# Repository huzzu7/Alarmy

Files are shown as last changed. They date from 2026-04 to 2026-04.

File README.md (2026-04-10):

# Alarmy

An Arduino-based running alarm clock that combines standard alarm clock functionality with motion, proximity sensing, and embedded UI design.

Alarmy was built as an embedded design project with the goal of making alarms harder to ignore. The system keeps real time using a DS1302 RTC, allows the user to set the clock and alarm through a rotary encoder and buttons, stores alarm settings in EEPROM, drives a buzzer and motor for alarm output, and uses an IR emitter and photodiode sensing setup for proximity detection.

## Features

- Real-time clock using a **DS1302 RTC**
- 16x2 **Waveshare RGB LCD** interface
- **KY-040 rotary encoder** with pushbutton for editing values
- External pushbutton for mode changes and alarm dismissal
- **Weekday-based alarm scheduling**
- **EEPROM-backed alarm persistence**
- Passive buzzer alarm output
- N20 motor-based physical alarm actuation
- IR emitter and photodiode proximity sensing using an **LM393 comparator board**
- Interrupt-based rotary encoder handling with Gray-code decoding
- Optimized LCD updates to reduce flicker and improve responsiveness

## Repository Structure

```text
Alarmy/
├── media/      # Project photos / demo images
├── cad/        # Mechanical design files / 3D models
├── pcb/        # PCB design files
└── src/
    └── alarmy.ino
```

## Hardware

Current hardware used in the prototype:

- Arduino Uno
- DS1302 RTC module
- Waveshare RGB LCD1602
- KY-040 rotary encoder
- External pushbutton
- Passive buzzer
- N20 DC motor
- MOSFET motor driver
- Flyback diode
- IR emitter and photodiode
- KY-037 board repurposed for its onboard LM393 comparator
- 470 µF bulk capacitor for voltage sag protection
- 0.1 µF capacitor for pushbutton RC filtering
- NiMH battery supply

## How It Works

The firmware is organized around three main UI modes:

- `MODE_NORMAL`
- `MODE_SET_TIME`
- `MODE_SET_ALARM`

The user edits values using the rotary encoder and its pushbutton, while the external button is used for major mode transitions. The RTC is polled periodically, alarm settings are stored in EEPROM, and the LCD only redraws changed characters to reduce flicker. The alarm logic supports weekday selection through a 7-bit day mask, and the buzzer uses a non-blocking repeating beep pattern. The motor output is also integrated into the alarm behavior.

## Pin Summary

From the current firmware:

- `pinA = 2`
- `pinB = 3`
- `buttonPin = A0`
- `rotButtonPin = 4`
- `buzzer = 8`
- `emitterPin = 9`
- `sensorPin = A1`
- `motorPin = 5`

RTC pins:

- `CE = 10`
- `IO = 11`
- `SCLK = 12`

## Software Notes

A few implementation details that matter:

- Rotary encoder input is handled using **interrupts**
- Encoder transitions are decoded using a **Gray-code transition table**
- Alarm settings are stored in EEPROM using a **versioned structure**
- LCD updates are throttled and diff-based to improve responsiveness
- Proximity detection compares emitter-off and emitter-on readings rather than relying on a single absolute measurement

## Building / Uploading

1. Open `src/alarmy.ino` in the Arduino IDE.
2. Install the required libraries:
   - `DS1302`
   - `EEPROM` (built-in)
   - `Waveshare_LCD1602_RGB`
3. Select the correct board and port for your Arduino.
4. Upload the sketch.
5. Connect the hardware according to the pin assignments above.

## CAD and PCB

- The `cad/` folder contains the mechanical design files for the enclosure and body.
- The `pcb/` folder contains the board design files as the electronics become more integrated.

The long-term goal is to move away from multiple header-connected external modules and toward a more compact PCB with more of the support circuitry integrated directly on-board.

## Media

Prototype photo:

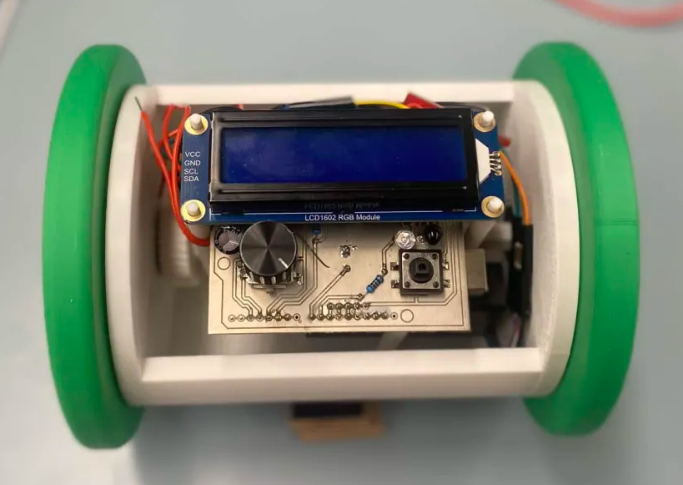
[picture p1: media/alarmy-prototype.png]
Alarmy prototype


PCB screenshot:

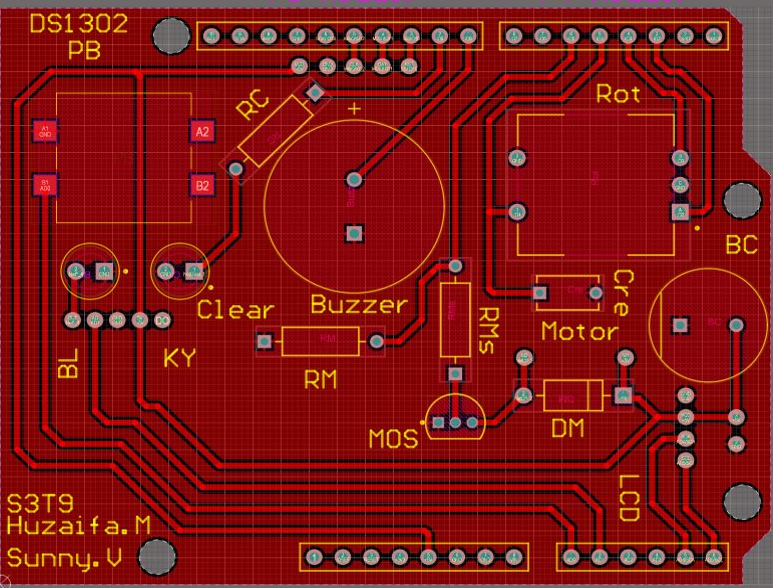
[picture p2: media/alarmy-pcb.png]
Alarmy screenshot


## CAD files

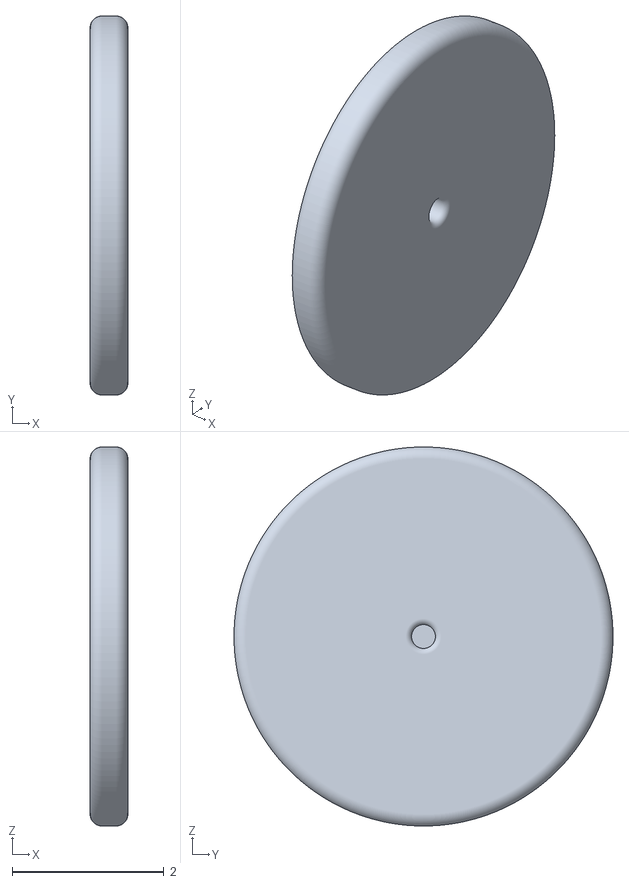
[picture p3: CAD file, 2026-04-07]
cad/wheel.stl
0.5 x 5.00 x 5.00

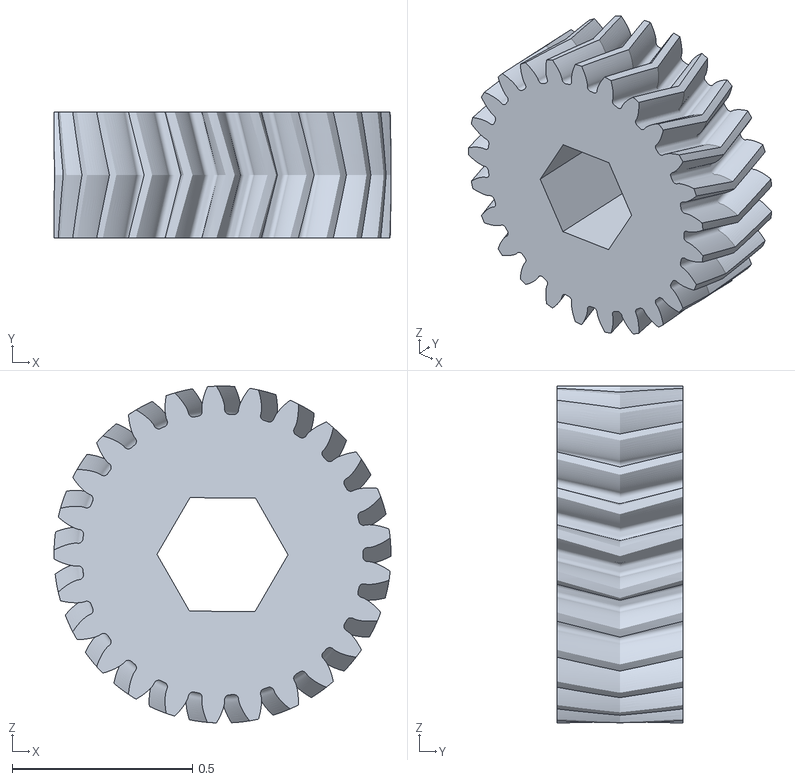
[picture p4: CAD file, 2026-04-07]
cad/driven_gear.stl
0.935 x 0.35 x 0.935

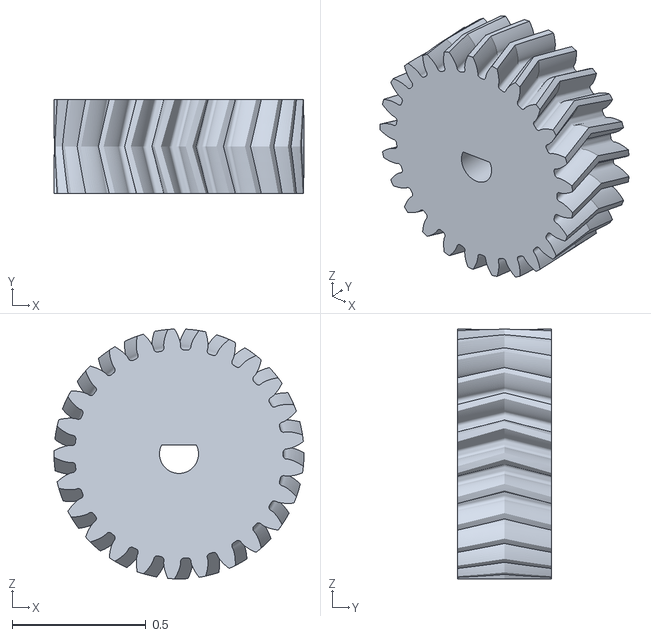
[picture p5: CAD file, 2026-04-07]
cad/driving_gear.stl
0.935 x 0.35 x 0.935

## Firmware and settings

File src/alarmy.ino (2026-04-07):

#include <Wire.h>
#include <EEPROM.h>
#include "Waveshare_LCD1602_RGB.h"
#include <DS1302.h>

// ---------------- Pins ----------------
const int pinA = 2;
const int pinB = 3;
const int buttonPin = A0;
const int rotButtonPin = 4;
const int buzzer = 8;
const int emitterPin = 9;
const int sensorPin = A1;
const int motorPin = 5;

// ---------------- DS1302 pins ----------------
const int kCePin   = 10;
const int kIoPin   = 11;
const int kSclkPin = 12;

DS1302 rtc(kCePin, kIoPin, kSclkPin);

// ---------------- LCD ----------------
Waveshare_LCD1602_RGB lcd(16, 2);

// ---------------- Custom underlined weekday chars ----------------
// slots:
// 0 = M
// 1 = T
// 2 = W
// 3 = F
// 4 = S
byte UL_M[8] = {
  B10001,
  B11011,
  B10101,
  B10001,
  B10001,
  B10001,
  B00000,
  B11111
};

byte UL_T[8] = {
  B11111,
  B00100,
  B00100,
  B00100,
  B00100,
  B00100,
  B00000,
  B11111
};

byte UL_W[8] = {
  B10001,
  B10001,
  B10001,
  B10101,
  B10101,
  B01010,
  B00000,
  B11111
};

byte UL_F[8] = {
  B11111,
  B10000,
  B10000,
  B11110,
  B10000,
  B10000,
  B00000,
  B11111
};

byte UL_S[8] = {
  B01111,
  B10000,
  B10000,
  B01110,
  B00001,
  B00001,
  B11110,
  B11111
};

// ---------------- Modes ----------------
enum UiMode {
  MODE_NORMAL,
  MODE_SET_TIME,
  MODE_SET_ALARM
};

UiMode mode = MODE_NORMAL;

// ---------------- Current time/date ----------------
int currentHour = 14;
int currentMinute = 30;
int currentDay = Time::kSunday;
int currentMonth = 3;
int currentDate = 15;
int currentYear = 2026;

// ---------------- Alarm ----------------
int alarmHour = 7;
int alarmMinute = 0;

// bit0=Mon, bit1=Tue, ..., bit6=Sun
uint8_t alarmDaysMask = 0x7F;

// ---------------- Photodiode sensing ----------------
int baselineSignal = 0;
const int buffer = 50;
const int detectionThreshold = 100;
bool proxDetected = false;
unsigned long lastProximitySample = 0;
const unsigned long proximitySamplePeriodMs = 15;

// ---------------- EEPROM layout ----------------
struct AlarmDataV2 {
  uint8_t magic;
  uint8_t hour;
  uint8_t minute;
  uint8_t daysMask;
};

struct AlarmDataV1 {
  uint8_t magic;
  uint8_t hour;
  uint8_t minute;
};

const uint8_t ALARM_MAGIC_V2 = 0xA8;
const uint8_t ALARM_MAGIC_V1 = 0xA7;
const int EEPROM_ADDR_ALARM = 0;

// ---------------- Button state ----------------
int lastButtonState = HIGH;
int lastRotButtonState = HIGH;
unsigned long lastButtonTime = 0;
unsigned long lastRotButtonTime = 0;
const unsigned long buttonDebounceMs = 30;

// ---------------- Encoder state ----------------
volatile int8_t encoderAcc = 0;
volatile uint8_t encoderState = 0;

const int8_t transitionTable[16] = {
  0, +1, -1,  0,
  -1,  0,  0, +1,
  +1,  0,  0, -1,
   0, -1, +1,  0
};

// ---------------- UI state ----------------
// MODE_SET_TIME:
// 0 = hours, 1 = minutes, 2 = AM/PM, 3 = day, 4 = month, 5 = date
//
// MODE_SET_ALARM:
// 0 = hours, 1 = minutes, 2 = AM/PM,
// 3 = Mon, 4 = Tue, 5 = Wed, 6 = Thu, 7 = Fri, 8 = Sat, 9 = Sun
int editIndex = 0;

// ---------------- LCD refresh control ----------------
bool displayDirty = true;
UiMode lastRenderedMode = MODE_SET_ALARM;
unsigned long lastLcdUpdate = 0;
const unsigned long lcdUpdatePeriod = 50;

// ---------------- Software blink ----------------
bool blinkVisible = true;
unsigned long lastBlinkToggle = 0;
const unsigned long blinkPeriod = 400;

// ---------------- LCD line cache ----------------
char lastLine1[17] = "                ";
char lastLine2[17] = "                ";

// ---------------- RTC sync timing ----------------
unsigned long lastRtcPoll = 0;
const unsigned long rtcPollPeriodMs = 250;

// ---------------- Helpers ----------------
void fillLine(char *line) {
  for (int i = 0; i < 16; i++) line[i] = ' ';
  line[16] = '\0';
}

bool fallingEdgeDebounced(int pin, int &lastState, unsigned long &lastTimeMs) {
  int currentState = digitalRead(pin);
  bool fell = false;

  if (lastState == HIGH && currentState == LOW) {
    unsigned long now = millis();
    if (now - lastTimeMs >= buttonDebounceMs) {
      fell = true;
      lastTimeMs = now;
    }
  }

  lastState = currentState;
  return fell;
}

int getDisplayHour12From(int hour24) {
  int h = hour24 % 12;
  if (h == 0) h = 12;
  return h;
}

bool isPMFrom(int hour24) {
  return hour24 >= 12;
}

void setFromDisplayHour12AndPeriod(int displayHour12, bool pm, int &hour24) {
  if (displayHour12 == 12) {
    hour24 = pm ? 12 : 0;
  } else {
    hour24 = pm ? (displayHour12 + 12) : displayHour12;
  }
}

const char* dayShort(uint8_t day) {
  switch (day) {
    case Time::kSunday:    return "Sun";
    case Time::kMonday:    return "Mon";
    case Time::kTuesday:   return "Tue";
    case Time::kWednesday: return "Wed";
    case Time::kThursday:  return "Thu";
    case Time::kFriday:    return "Fri";
    case Time::kSaturday:  return "Sat";
  }
  return "???";
}

const char* monthShort(uint8_t mon) {
  switch (mon) {
    case 1:  return "Jan";
    case 2:  return "Feb";
    case 3:  return "Mar";
    case 4:  return "Apr";
    case 5:  return "May";
    case 6:  return "Jun";
    case 7:  return "Jul";
    case 8:  return "Aug";
    case 9:  return "Sep";
    case 10: return "Oct";
    case 11: return "Nov";
    case 12: return "Dec";
  }
  return "???";
}

int daysInMonth(int year, int month) {
  switch (month) {
    case 1:  return 31;
    case 2: {
      bool leap = ((year % 4 == 0) && (year % 100 != 0)) || (year % 400 == 0);
      return leap ? 29 : 28;
    }
    case 3:  return 31;
    case 4:  return 30;
    case 5:  return 31;
    case 6:  return 30;
    case 7:  return 31;
    case 8:  return 31;
    case 9:  return 30;
    case 10: return 31;
    case 11: return 30;
    case 12: return 31;
  }
  return 31;
}

void clampCurrentDateToMonth() {
  int dim = daysInMonth(currentYear, currentMonth);
  if (currentDate > dim) currentDate = dim;
  if (currentDate < 1) currentDate = 1;
}

bool alarmDayEnabled(int dayIdxMon0ToSun6) {
  return (alarmDaysMask & (1 << dayIdxMon0ToSun6)) != 0;
}

void setAlarmDayEnabled(int dayIdxMon0ToSun6, bool enabled) {
  if (enabled) alarmDaysMask |= (1 << dayIdxMon0ToSun6);
  else         alarmDaysMask &= ~(1 << dayIdxMon0ToSun6);
  displayDirty = true;
}

char normalDayLetter(int dayIdxMon0ToSun6) {
  const char letters[7] = {'M', 'T', 'W', 'T', 'F', 'S', 'S'};
  return letters[dayIdxMon0ToSun6];
}

uint8_t underlinedCharForDay(int dayIdxMon0ToSun6) {
  switch (dayIdxMon0ToSun6) {
    case 0: return 0;
    case 1: return 1;
    case 2: return 2;
    case 3: return 1;
    case 4: return 3;
    case 5: return 4;
    case 6: return 4;
  }
  return 0;
}

//////////////////////////
// BUZZER SOUNDS
//////////////////////////

bool alarmRinging = false;
bool alarmLatched = false;  // prevents retrigger within same minute

// non-blocking Casio alarm state
unsigned long alarmToneStartedAt = 0;
unsigned long alarmPhaseStartedAt = 0;
int alarmPhase = 0;
int alarmCycleCount = 0;

void calibratePhotodiodeBaseline() {
  Serial.println("Calibrating baseline... Keep sensor clear!");
  long total = 0;

  for (int i = 0; i < 10; i++) {
    digitalWrite(emitterPin, LOW);
    delay(10);
    int offVal = analogRead(sensorPin);

    digitalWrite(emitterPin, HIGH);
    delay(1);
    int onVal = analogRead(sensorPin);

    total += abs(onVal - offVal);
  }

  baselineSignal = total / 10;
  Serial.print("Baseline Leakage detected at: ");
  Serial.println(baselineSignal);
  digitalWrite(emitterPin, LOW);
}

bool readProximityDetected() {
  unsigned long now = millis();
  if (now - lastProximitySample < proximitySamplePeriodMs) {
    return proxDetected;
  }
  lastProximitySample = now;

  digitalWrite(emitterPin, LOW);
  delayMicroseconds(9000);
  int ambientVal = analogRead(sensorPin);

  digitalWrite(emitterPin, HIGH);
  delayMicroseconds(1000);
  int activeVal = analogRead(sensorPin);

  int currentSignal = abs(activeVal - ambientVal);
  int triggerLevel = baselineSignal + buffer;
  if (triggerLevel < detectionThreshold) triggerLevel = detectionThreshold;

  proxDetected = (currentSignal > triggerLevel);

  digitalWrite(emitterPin, LOW);
  return proxDetected;
}

void startCasioAlarm() {
  alarmRinging = true;
  proxDetected = false;
  alarmPhase = 0;
  alarmCycleCount = 0;
  alarmPhaseStartedAt = millis();
  alarmToneStartedAt = 0;
}

void stopCasioAlarm() {
  alarmRinging = false;
  proxDetected = false;
  alarmPhase = 0;
  alarmCycleCount = 0;
  noTone(buzzer);
  digitalWrite(emitterPin, LOW);
}

void serviceCasioAlarm() {
  unsigned long now = millis();

  switch (alarmPhase) {
    case 0: // first beep on (100 ms)
      if (alarmToneStartedAt == 0) {
        tone(buzzer, 4096);
        alarmToneStartedAt = now;
        alarmPhaseStartedAt = now;
      }
      if (now - alarmPhaseStartedAt >= 100) {
        noTone(buzzer);
        alarmPhase = 1;
        alarmPhaseStartedAt = now;
        alarmToneStartedAt = 0;
      }
      break;

    case 1: // gap 50 ms
      if (now - alarmPhaseStartedAt >= 50) {
        alarmPhase = 2;
        alarmPhaseStartedAt = now;
      }
      break;

    case 2: // second beep on (100 ms)
      if (alarmToneStartedAt == 0) {
        tone(buzzer, 4096);
        alarmToneStartedAt = now;
        alarmPhaseStartedAt = now;
      }
      if (now - alarmPhaseStartedAt >= 100) {
        noTone(buzzer);
        alarmPhase = 3;
        alarmPhaseStartedAt = now;
        alarmToneStartedAt = 0;
      }
      break;

    case 3: // gap 200 ms to complete the original 300 ms delay after second beep
      if (now - alarmPhaseStartedAt >= 200) {
        alarmCycleCount++;
        if (alarmCycleCount >= 4) {
          alarmCycleCount = 0;
        }
        alarmPhase = 0;
        alarmPhaseStartedAt = now;
      }
      break;
  }
}

void glassClick() {
  tone(buzzer, 3200, 12);
}

void rotaryCW() {
  tone(buzzer, 2600, 7);
}

void rotaryCCW() {
  tone(buzzer, 2000, 7);
}

void successMini() {
  tone(buzzer, 1700, 30);
  delay(35);
  tone(buzzer, 2300, 40);
}

void loadAlarmFromEEPROM() {
  AlarmDataV2 dataV2;
  EEPROM.get(EEPROM_ADDR_ALARM, dataV2);

  if (dataV2.magic == ALARM_MAGIC_V2 &&
      dataV2.hour < 24 &&
      dataV2.minute < 60 &&
      (dataV2.daysMask & 0x80) == 0) {
    alarmHour = dataV2.hour;
    alarmMinute = dataV2.minute;
    alarmDaysMask = dataV2.daysMask;
    if (alarmDaysMask == 0) alarmDaysMask = 0x7F;
    return;
  }

  AlarmDataV1 dataV1;
  EEPROM.get(EEPROM_ADDR_ALARM, dataV1);

  if (dataV1.magic == ALARM_MAGIC_V1 &&
      dataV1.hour < 24 &&
      dataV1.minute < 60) {
    alarmHour = dataV1.hour;
    alarmMinute = dataV1.minute;
    alarmDaysMask = 0x7F;
    return;
  }

  alarmHour = 7;
  alarmMinute = 0;
  alarmDaysMask = 0x7F;
}

void saveAlarmToEEPROM() {
  AlarmDataV2 data;
  data.magic = ALARM_MAGIC_V2;
  data.hour = (uint8_t)alarmHour;
  data.minute = (uint8_t)alarmMinute;
  data.daysMask = alarmDaysMask & 0x7F;
  EEPROM.put(EEPROM_ADDR_ALARM, data);
}

void setBacklightForMode() {
  lcd.setRGB(255, 100, 20);
}

void updateLineIfChanged(int row, const char *newText, char *oldText) {
  for (int i = 0; i < 16; i++) {
    if (newText[i] != oldText[i]) {
      lcd.setCursor(i, row);
      char c[2] = { newText[i], '\0' };
      lcd.send_string(c);
      oldText[i] = newText[i];
    }
  }
  oldText[16] = '\0';
}

void clearLineCaches() {
  for (int i = 0; i < 16; i++) {
    lastLine1[i] = 0x7F;
    lastLine2[i] = 0x7F;
  }
  lastLine1[16] = '\0';
  lastLine2[16] = '\0';
}

void applyFieldDeltaTo(int idx, int delta, int &hour24, int &minuteVal) {
  if (delta == 0) return;

  int displayHour = getDisplayHour12From(hour24);
  bool pm = isPMFrom(hour24);

  switch (idx) {
    case 0:
      displayHour += delta;
      while (displayHour > 12) displayHour -= 12;
      while (displayHour < 1)  displayHour += 12;
      setFromDisplayHour12AndPeriod(displayHour, pm, hour24);
      break;

    case 1:
      minuteVal += delta;
      while (minuteVal > 59) minuteVal -= 60;
      while (minuteVal < 0)  minuteVal += 60;
      break;

    case 2:
      if (pm) hour24 -= 12;
      else    hour24 += 12;
      break;
  }

  displayDirty = true;
}

void applyDateFieldDelta(int idx, int delta) {
  if (delta == 0) return;

  switch (idx) {
    case 3:
      currentDay += delta;
      while (currentDay > Time::kSaturday) currentDay -= 7;
      while (currentDay < Time::kSunday)   currentDay += 7;
      break;

    case 4:
      currentMonth += delta;
      while (currentMonth > 12) currentMonth -= 12;
      while (currentMonth < 1)  currentMonth += 12;
      clampCurrentDateToMonth();
      break;

    case 5: {
      currentDate += delta;
      int dim = daysInMonth(currentYear, currentMonth);
      while (currentDate > dim) currentDate -= dim;
      while (currentDate < 1)   currentDate += dim;
      break;
    }
  }

  displayDirty = true;
}

void renderTimeLine(int hour24, int minuteVal, bool editModeActive) {
  char line1[17];
  fillLine(line1);

  int displayHour = getDisplayHour12From(hour24);
  bool pm = isPMFrom(hour24);

  char hourField[3];
  char minuteField[3];
  char periodField[3];

  snprintf(hourField, sizeof(hourField), "%02d", displayHour);
  snprintf(minuteField, sizeof(minuteField), "%02d", minuteVal);
  snprintf(periodField, sizeof(periodField), "%s", pm ? "PM" : "AM");

  if (editModeActive && !blinkVisible) {
    if (editIndex == 0) {
      hourField[0] = ' ';
      hourField[1] = ' ';
    } else if (editIndex == 1) {
      minuteField[0] = ' ';
      minuteField[1] = ' ';
    } else if (editIndex == 2) {
      periodField[0] = ' ';
      periodField[1] = ' ';
    }
  }

  line1[4]  = hourField[0];
  line1[5]  = hourField[1];
  line1[6]  = ':';
  line1[7]  = minuteField[0];
  line1[8]  = minuteField[1];
  line1[9]  = ' ';
  line1[10] = periodField[0];
  line1[11] = periodField[1];

  updateLineIfChanged(0, line1, lastLine1);
}

void renderDateLine(bool editModeActive) {
  char line2[17];
  fillLine(line2);

  char dayField[4];
  char monthField[4];
  char dateField[3];

  snprintf(dayField, sizeof(dayField), "%s", dayShort(currentDay));
  snprintf(monthField, sizeof(monthField), "%s", monthShort(currentMonth));
  snprintf(dateField, sizeof(dateField), "%02d", currentDate);

  if (editModeActive && !blinkVisible) {
    if (editIndex == 3) {
      dayField[0] = ' ';
      dayField[1] = ' ';
      dayField[2] = ' ';
    } else if (editIndex == 4) {
      monthField[0] = ' ';
      monthField[1] = ' ';
      monthField[2] = ' ';
    } else if (editIndex == 5) {
      dateField[0] = ' ';
      dateField[1] = ' ';
    }
  }

  line2[0]  = dayField[0];
  line2[1]  = dayField[1];
  line2[2]  = dayField[2];
  line2[9]  = monthField[0];
  line2[10] = monthField[1];
  line2[11] = monthField[2];
  line2[13] = dateField[0];
  line2[14] = dateField[1];

  updateLineIfChanged(1, line2, lastLine2);
}

void renderAlarmDaysLine() {
  char line2[17];
  fillLine(line2);

  const uint8_t pos[7] = {1, 3, 5, 7, 9, 11, 13};

  for (int i = 0; i < 7; i++) {
    if (editIndex == (3 + i) && !blinkVisible) {
      line2[pos[i]] = ' ';
    } else if (alarmDayEnabled(i)) {
      line2[pos[i]] = '~';
    } else {
      line2[pos[i]] = normalDayLetter(i);
    }
  }

  updateLineIfChanged(1, line2, lastLine2);

  for (int i = 0; i < 7; i++) {
    if (editIndex == (3 + i) && !blinkVisible) continue;

    if (alarmDayEnabled(i)) {
      lcd.setCursor(pos[i], 1);
      lcd.write_char(underlinedCharForDay(i));
      lastLine2[pos[i]] = '~';
    }
  }
}

void renderNormalMode(bool fullRedraw) {
  if (fullRedraw) clearLineCaches();
  renderTimeLine(currentHour, currentMinute, false);
  renderDateLine(false);
  lcd.noCursor();
  lcd.stopBlink();
}

void renderSetTimeMode(bool fullRedraw) {
  if (fullRedraw) clearLineCaches();
  renderTimeLine(currentHour, currentMinute, true);
  renderDateLine(true);
  lcd.noCursor();
  lcd.stopBlink();
}

void renderSetAlarmMode(bool fullRedraw) {
  if (fullRedraw) clearLineCaches();
  renderTimeLine(alarmHour, alarmMinute, true);
  renderAlarmDaysLine();
  lcd.noCursor();
  lcd.stopBlink();
}

void updateDisplayIfNeeded() {
  unsigned long now = millis();
  if (!displayDirty) return;
  if (now - lastLcdUpdate < lcdUpdatePeriod) return;

  lastLcdUpdate = now;
  bool fullRedraw = (mode != lastRenderedMode);

  if (mode == MODE_NORMAL) {
    renderNormalMode(fullRedraw);
  } else if (mode == MODE_SET_TIME) {
    renderSetTimeMode(fullRedraw);
  } else {
    renderSetAlarmMode(fullRedraw);
  }

  lastRenderedMode = mode;
  displayDirty = false;
}

// ---------------- RTC helpers ----------------
void syncCurrentDateTimeFromRTC() {
  Time t = rtc.time();

  if (t.hr >= 0 && t.hr < 24 &&
      t.min >= 0 && t.min < 60 &&
      t.mon >= 1 && t.mon <= 12 &&
      t.date >= 1 && t.date <= 31 &&
      t.day >= Time::kSunday && t.day <= Time::kSaturday) {

    bool changed = false;

    if (t.hr != currentHour)    { currentHour = t.hr; changed = true; }
    if (t.min != currentMinute) { currentMinute = t.min; changed = true; }
    if (t.day != currentDay)    { currentDay = t.day; changed = true; }
    if (t.mon != currentMonth)  { currentMonth = t.mon; changed = true; }
    if (t.date != currentDate)  { currentDate = t.date; changed = true; }
    if (t.yr != currentYear)    { currentYear = t.yr; changed = true; }

    if (changed) displayDirty = true;
  }
}

void writeEditedDateTimeToRTC() {
  clampCurrentDateToMonth();
  Time t = rtc.time();

  Time newTime(
    currentYear,
    currentMonth,
    currentDate,
    currentHour,
    currentMinute,
    t.sec,
    (Time::Day)currentDay
  );

  rtc.time(newTime);
}

// ---------------- Mode transitions ----------------
void enterTimeMode() {
  syncCurrentDateTimeFromRTC();
  mode = MODE_SET_TIME;
  editIndex = 0;
  blinkVisible = true;
  lastBlinkToggle = millis();
  setBacklightForMode();
  displayDirty = true;
}

void enterAlarmMode() {
  writeEditedDateTimeToRTC();
  successMini();
  mode = MODE_SET_ALARM;
  editIndex = 0;
  blinkVisible = true;
  lastBlinkToggle = millis();
  setBacklightForMode();
  displayDirty = true;
}

void exitToNormalMode() {
  saveAlarmToEEPROM();
  successMini();
  mode = MODE_NORMAL;
  blinkVisible = true;
  setBacklightForMode();
  displayDirty = true;
}

// ---------------- Encoder ISR ----------------
void updateEncoderISR() {
  uint8_t portd = PIND;
  uint8_t a = (portd >> 2) & 0x01;
  uint8_t b = (portd >> 3) & 0x01;
  uint8_t newState = (a << 1) | b;
  uint8_t index = (encoderState << 2) | newState;

  encoderAcc += transitionTable[index];
  encoderState = newState;
}
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
void loop() {

  // ---------------- Alarm trigger ----------------
  if (!alarmRinging && mode == MODE_NORMAL) {
    int dayIdx = (currentDay == Time::kSunday) ? 6 : (currentDay - 1);

    if (!alarmLatched &&
        alarmDayEnabled(dayIdx) &&
        currentHour == alarmHour &&
        currentMinute == alarmMinute) {
      startCasioAlarm();
      alarmLatched = true;
    }

    // reset latch when minute changes
    if (currentMinute != alarmMinute) {
      alarmLatched = false;
    }
  }

  if (alarmRinging) {
    serviceCasioAlarm();

    bool buttonPressed =
      fallingEdgeDebounced(buttonPin, lastButtonState, lastButtonTime) ||
      fallingEdgeDebounced(rotButtonPin, lastRotButtonState, lastRotButtonTime);

    bool proximityTriggered = readProximityDetected();

    

    if (proximityTriggered){
      digitalWrite(motorPin,HIGH);
    }

    if (buttonPressed) {
      stopCasioAlarm();
      digitalWrite(motorPin,LOW);

      return;
    }


  } else {
    digitalWrite(emitterPin, LOW);
    
  }

  if (mode == MODE_NORMAL) {
    unsigned long now = millis();
    if (now - lastRtcPoll >= rtcPollPeriodMs) {
      lastRtcPoll = now;
      syncCurrentDateTimeFromRTC();
    }
  }

  if (mode != MODE_NORMAL) {
    unsigned long now = millis();
    if (now - lastBlinkToggle >= blinkPeriod) {
      lastBlinkToggle = now;
      blinkVisible = !blinkVisible;
      displayDirty = true;
    }
  }

  int8_t acc;
  noInterrupts();
  acc = encoderAcc;
  encoderAcc = 0;
  interrupts();

  static int subStepAccumulator = 0;
  subStepAccumulator += acc;

  int step = 0;
  while (subStepAccumulator >= 4) {
    step++;
    subStepAccumulator -= 4;
  }
  while (subStepAccumulator <= -4) {
    step--;
    subStepAccumulator += 4;
  }

  if (step != 0) {
    if (step > 0) rotaryCW();
    else rotaryCCW();

    blinkVisible = true;
    lastBlinkToggle = millis();

    if (mode == MODE_SET_TIME) {
      if (editIndex <= 2) {
        applyFieldDeltaTo(editIndex, step, currentHour, currentMinute);
      } else {
        applyDateFieldDelta(editIndex, step);
      }
    } else if (mode == MODE_SET_ALARM) {
      if (editIndex <= 2) {
        applyFieldDeltaTo(editIndex, step, alarmHour, alarmMinute);
      } else {
        int dayIdx = editIndex - 3;
        setAlarmDayEnabled(dayIdx, !alarmDayEnabled(dayIdx));
      }
    }
  }

  if (mode == MODE_NORMAL) {
    if (fallingEdgeDebounced(buttonPin, lastButtonState, lastButtonTime)) {
      glassClick();
      enterTimeMode();
      return;
    }
  } else if (mode == MODE_SET_TIME) {
    if (fallingEdgeDebounced(rotButtonPin, lastRotButtonState, lastRotButtonTime)) {
      glassClick();
      editIndex = (editIndex + 1) % 6;
      blinkVisible = true;
      lastBlinkToggle = millis();
      displayDirty = true;
    }

    if (fallingEdgeDebounced(buttonPin, lastButtonState, lastButtonTime)) {
      glassClick();
      enterAlarmMode();
      return;
    }
  } else if (mode == MODE_SET_ALARM) {
    if (fallingEdgeDebounced(rotButtonPin, lastRotButtonState, lastRotButtonTime)) {
      glassClick();
      editIndex = (editIndex + 1) % 10;
      blinkVisible = true;
      lastBlinkToggle = millis();
      displayDirty = true;
    }

    if (fallingEdgeDebounced(buttonPin, lastButtonState, lastButtonTime)) {
      glassClick();
      exitToNormalMode();
      return;
    }
  }

  updateDisplayIfNeeded();
}

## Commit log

2026-04-07 stl files upload
    [driven_gear.stl, driving_gear.stl, wheel.stl]
2026-04-08 Uploaded PCB files
    [Alarmy.PcbDoc, Alarmy.SchDoc]
